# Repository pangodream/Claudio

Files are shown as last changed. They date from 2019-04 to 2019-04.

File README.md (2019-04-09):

# Claudio
Claudio is a wake up alarm based on ESP32 by Espressif Systems and programmed with Arduino IDE

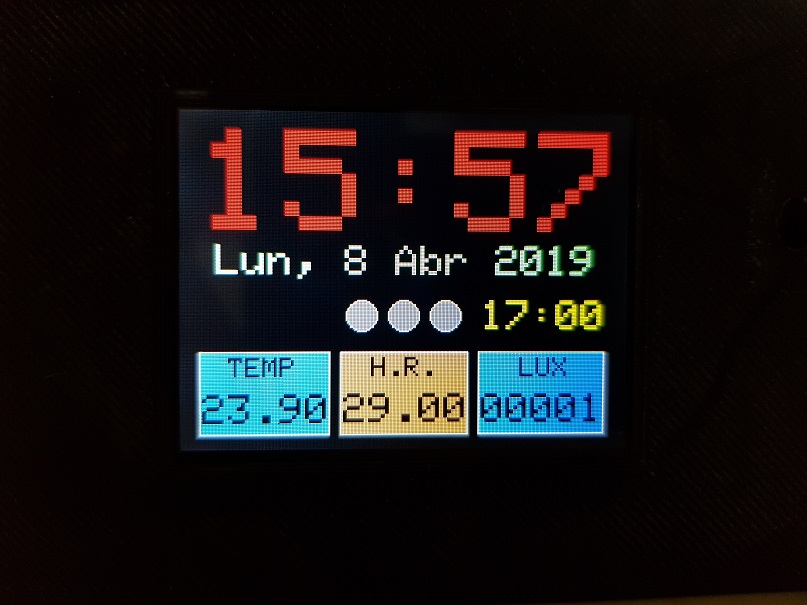
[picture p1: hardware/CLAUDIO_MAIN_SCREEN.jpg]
Claudio Main Screen


Folders:

/          Arduino IDE code

/box       Prototype print 3d files

/hardware  Hardware pictures

More info and demos at: https://www.youtube.com/watch?v=NURag-YYxIY

# WIRING DIAGRAM
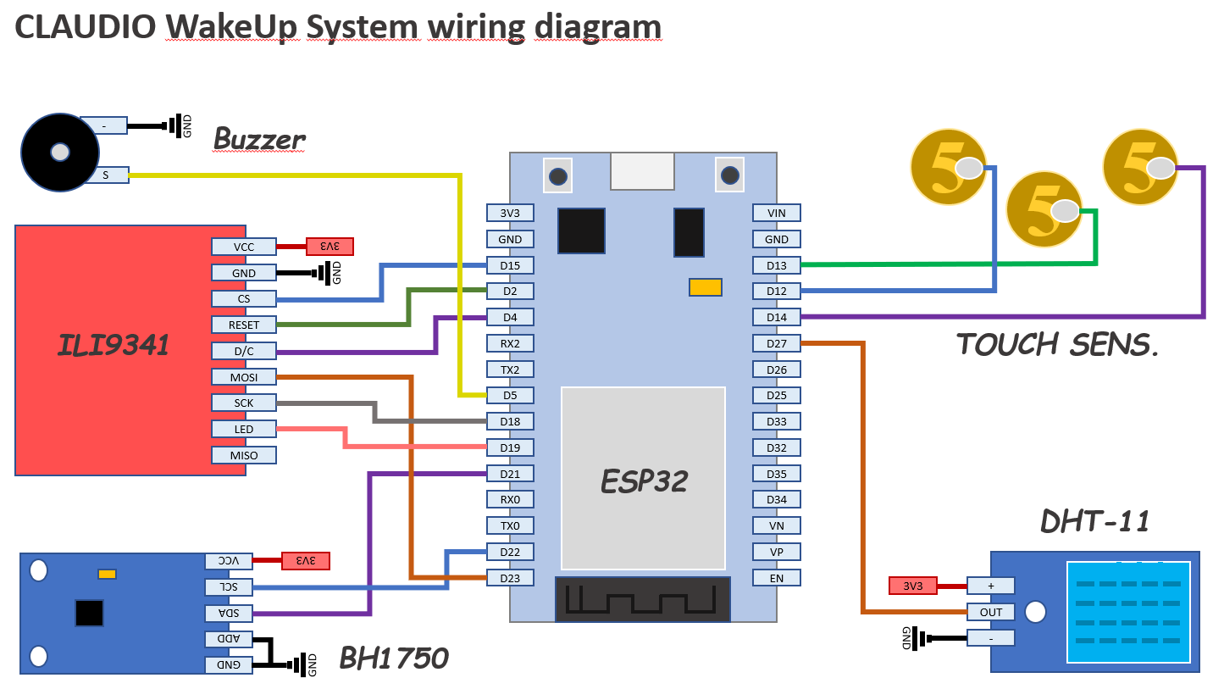
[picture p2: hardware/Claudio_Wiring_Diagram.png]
Claudio Main Screen


# REMOTE CONFIGURATION
By default, Claudio is listening on port 1234 for incoming connections. 

These connections allow a remote system to configure or perform some actions on the system. (Change parameters, Set alarm time, Deactivate alarm, ...)

Once the remote client is connected to claudio, commands are sent concatenated to items and values all in upper case. 

For instance, if we want to know the number of beeps to sound during an alarm, we must use the command GET followed by the item ALBEEP:
```bash
GETALBEEP
```
 If all succeed, the system will reply
```bash
90
```
which is the value cofigured for this parameter. Otherwise, the system could reply "Invalid Command" or "Invalid Item"

If we want to change the value of this parameter, for instance to 120, we should send
```bash
SETALBEEP120
```
and the system should reply
```bash
OK
```

## Available commands 
**GET**
Retrieves the value of the specified item.

**SET**
Stores the specified value in the specified item.

**GET**
Retrieves all the items value in a concatenated string ITEM1 + VALUE1 + ; + ... + ITEMn + VALUEn + ; 

For instance:
```bash
BOOTWT5;TOUCHR120;THTCHR70;THTCHM65;THTCHL65;LTCHTH12;...
```

**RST**
Reboot the system.

**TSS**
Stops and deactivates alarm, even while alarm is being executed.

## Available items
**BOOTWT**

Number of seconds (aprox.) to wait after boot screen to start the normal operation

EEPROM stored: Yes

Default value: 20

**TOUCHR**

Number of readings to calculate sensor capacitance average value

EEPROM stored: Yes

Default value: 120

**THTCHR**

Average capacitance threshold value for Right sensor. Under this value the sensor is considered activated

EEPROM stored: Yes

Default value: 70

**THTCHM**

Average capacitance threshold value for Middle sensor. Under this value the sensor is considered activated

EEPROM stored: Yes

Default value: 65

**THTCHL**

Average capacitance threshold value for Left sensor. Under this value the sensor is considered activated

EEPROM stored: Yes

Default value: 65

**LTCHTH**

Long touch threshold. Number of tenths of a second to consider a sensor has been long touched.

EEPROM stored: Yes

Default value: 12   (1.2 secs)

**SNZMIN**

Number of minutes to postpone alarm time (Snooze)

EEPROM stored: Yes

Default value: 9

**ALBEEP**

Number of beeps to sound during alarm

EEPROM stored: Yes

Default value: 90

**MAXLUX**

Maximum lux value to take into account. Above this any value is just considered maximum value.

When ambient light reaches this value, the display backlight is set to 100% power. 

EEPROM stored: Yes

Default value: 20

**MINLUX**

Minimum lux value to take into account. Below this any value is just considered minimum value.

When ambient light goes down to this value, the display backlight is set to Minimun Brightness value. (see next item))

EEPROM stored: Yes

Default value: 0

**MINBRG**

When ambient light reaches its minimum value, display backlight power is set to this value.

This is commonly used to set the backlight level we want while sleeping. 

EEPROM stored: Yes

Default value: 10

**ALARHO**

Defines the hour part of alarm time 

EEPROM stored: No

Default value: No default value

**ALARMI**

Defines the minutes part of alarm time

EEPROM stored: No

Default value: No default value

**DOALAR**

Switch ON/OFF alarm by sending 1/0 value for this item

EEPROM stored: No

Default value: No default value

**ONALAR**

Indicates whether the alarm is beeping or not. As well, it stops alarm beeping if its value is set to 0

EEPROM stored: No

Default value: No default value

To test remote configuration capabilities you can use Claudio Remote, an Android app to change configuration values easily:
https://github.com/pangodream/ClaudioRemote

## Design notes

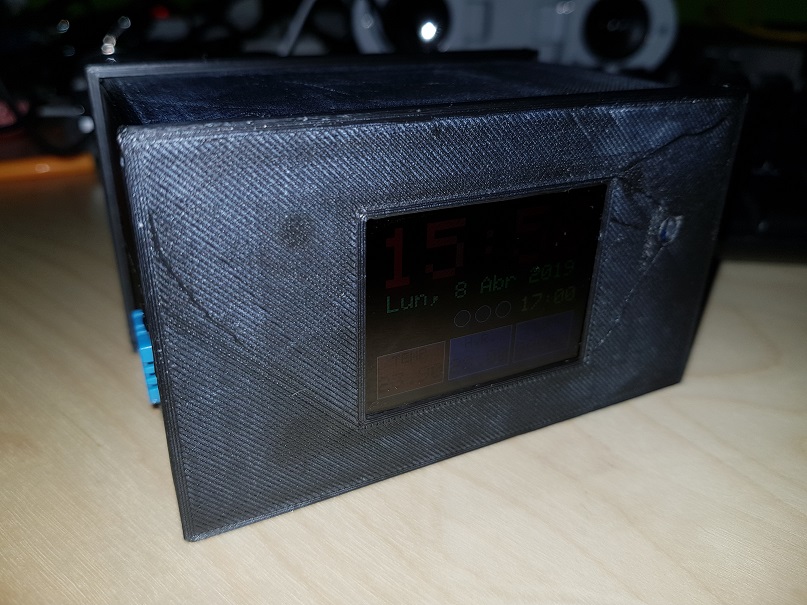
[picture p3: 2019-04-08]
hardware/CLAUDIO_PROTOTYPE_MOUNTED.jpg

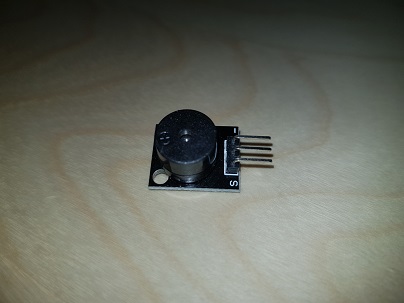
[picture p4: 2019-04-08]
hardware/PASSIVE_BUZZER.jpg

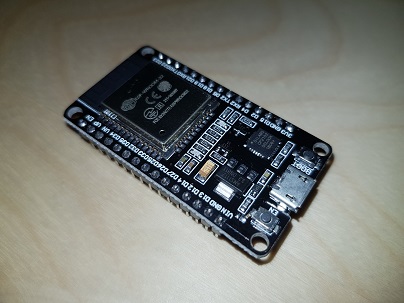
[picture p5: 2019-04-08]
hardware/ESP32_DEV_BOARD.jpg

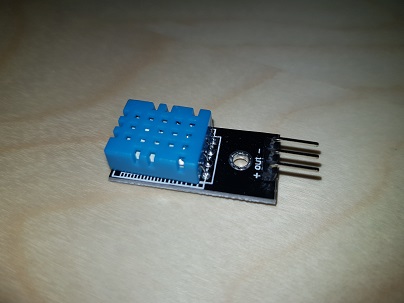
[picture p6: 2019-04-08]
hardware/DHT11_TEMP_HUMID_SENSOR.jpg

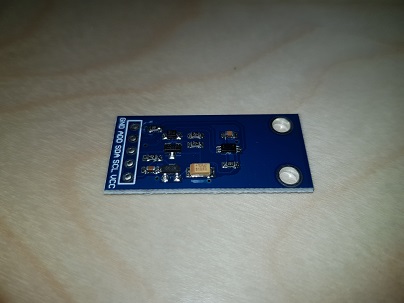
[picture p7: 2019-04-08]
hardware/BH1750FVI_LUX_METER.jpg

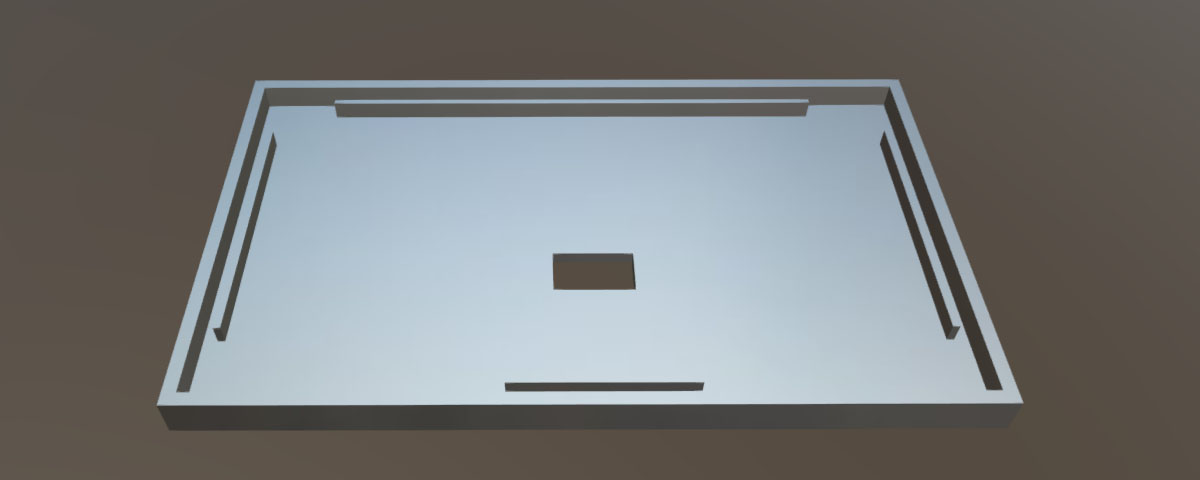
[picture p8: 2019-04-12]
box/ClaudioBoxBack.jpg

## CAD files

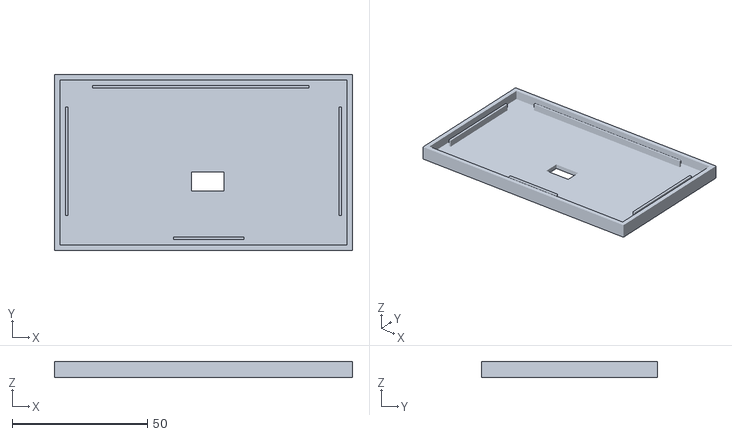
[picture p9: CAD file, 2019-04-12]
box/ClaudioBoxBack.stl
110.0 x 65.0 x 6.00

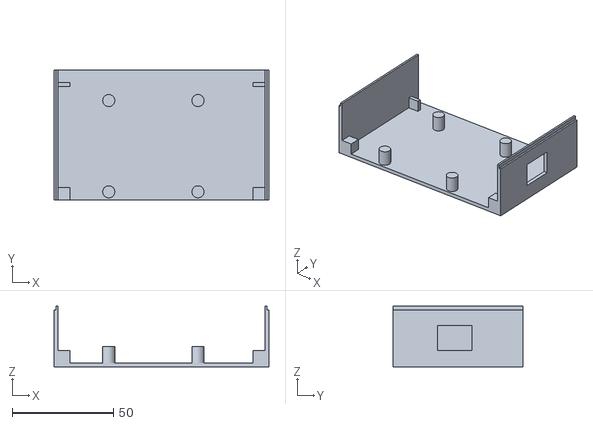
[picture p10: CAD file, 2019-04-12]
box/ClaudioBoxBase.stl
106.0 x 64.0 x 30.0

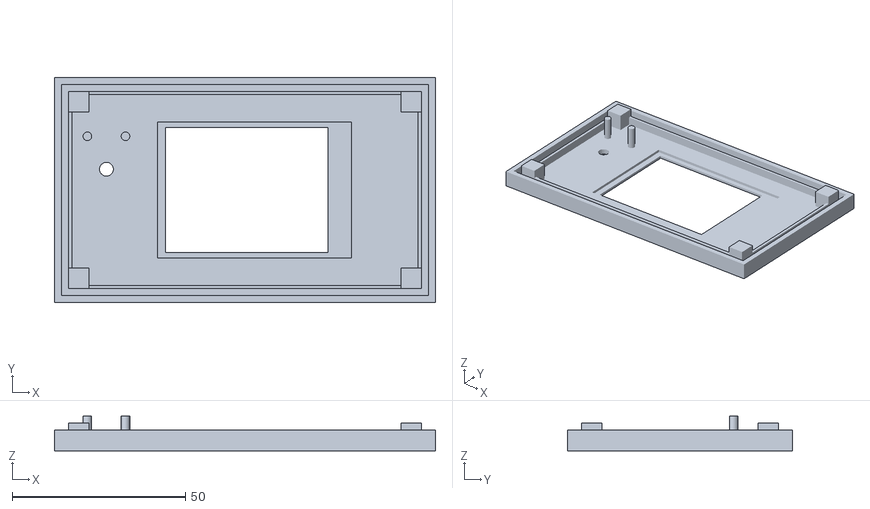
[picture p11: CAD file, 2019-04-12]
box/ClaudioBoxFront.stl
110.0 x 65.0 x 10.0

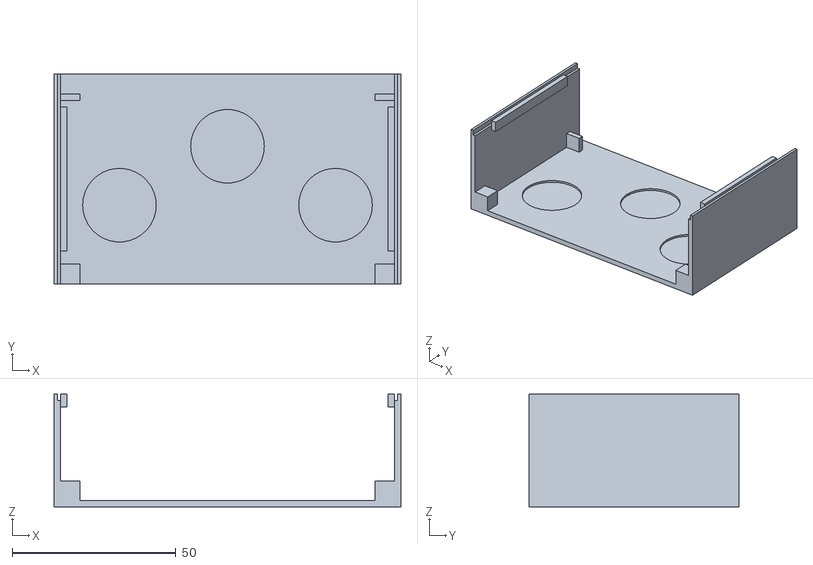
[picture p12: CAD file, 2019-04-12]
box/ClaudioBoxCover.stl
106.0 x 64.0 x 34.5

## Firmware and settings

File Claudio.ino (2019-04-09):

/**
 * GLOBAL PIN CONFIGURATION
 */

const int TFT_CS = 15;
const int TFT_DC = 4;
const int TFT_MOSI = 23;
const int TFT_SLK = 18;
const int TFT_RST = 2;
const int TFT_LED = 19;     
const int BUZZER = 5; 
const int LUX_SDA = 21;
const int LUX_SCL = 22;
const int DHT_OUT = 27;
/**
 * EEPROM libraries and resources
 */
#include "EEPROM.h"
#define EEPROM_SIZE 64
 
/**
 * ILI9341 TFT libraries and resources
 */
#include "SPI.h"
#include "Adafruit_GFX.h"
#include "Adafruit_ILI9341.h"
//                                      cs  dc  mosi slk rst
Adafruit_ILI9341 tft = Adafruit_ILI9341(TFT_CS, TFT_DC, TFT_MOSI, TFT_SLK, TFT_RST);

#define ILI9341_LCYAN   0x0418
#define ILI9341_LORANGE 0xFC08
#define ILI9341_LGREEN  0x87F0
#define ILI9341_LGRAY   0x8410

/**
 * BH1750 Lux meter libraries and resources
 */
#include <BH1750FVI.h>
// Create the Lightsensor instance
BH1750FVI LightSensor(BH1750FVI::k_DevModeContHighRes); 

/**
 * DHT-11 Temp and humidity sensor  libraries and resources
 */
#include "DHT.h"
#define DHTTYPE DHT11
DHT dht(DHT_OUT, DHTTYPE);       

/**    
 *  WIFI Libraries and resources   
 */
#include <WiFi.h>
//Absolute path to file containing WiFi credentials
//const char* ssid       = "MyApSSID";
//const char* password   = "MyApPassphrase";
#include <c:\datos\desarrollo\arduino\credentials.h>
const int connTimeout = 10; //Seconds

WiFiServer wifiServer(1234);


/** 
 *  TIME libraries and resources
 */
#include "time.h"
const char* ntpServer = "pool.ntp.org";
const long  gmtOffset_sec = 3600;
const int   daylightOffset_sec = 3600;
 
/**
 * PWM Constants
 */
const int freq = 5000;
const int tftledChannel = 0;
const int resolution = 8;
/**
 * TFT Display Constants 
 */
const int xTime = 14;
const int yTime = 14;
const int tftBG = ILI9341_BLACK;
const int tftTimeFG = ILI9341_RED;


 
/**
 * GLOBALS
 */
String   prevTime = "";
String   currTime = "";
String   prevDate = "";
String   currDate = ""; 
uint16_t prevLux = 0;
uint16_t currLux = 0;
float    prevTemp = 0;
float    currTemp = 0;
float    prevHumi = 0;
float    currHumi = 0;
bool     onWifi = false;
String   weekDays[] = {"", "Lun", "Mar", "Mie", "Jue", "Vie", "Sab", "Dom"};
String   months[] = {"", " Ene ", "Feb", "Mar", "Abr", "May", "Jun", "Jul", "Ago", "Sep", "Oct", "Nov", "Dic"};
int      pinTouchR = 14; 
int      pinTouchM = 13; 
int      pinTouchL = 12;
int      statusTouchR = 0;
int      statusTouchM = 0;
int      statusTouchL = 0;
ulong    lastTouchR;
ulong    lastTouchM;
ulong    lastTouchL;
bool     doAlarm;
String   alarmTime;
bool     onAlarm;
bool     waitingToTouch = false;
bool     onConfig = false;

//Configurable values
int      bootWait; //Seconds
int      touchReadings;
int      thresholdTouchR; 
int      thresholdTouchM; 
int      thresholdTouchL;
int      longTouchThreshold; // Tenths of second
int      snoozeMinutes;
int      alarmBeeps;
byte     maxLux;
byte     minLux;
byte     minBrightness;



void setup() {
  /**
   * Serial port
   */
  Serial.begin(115200);
  
  /**
   * EEPROM
   */
  EEPROM.begin(EEPROM_SIZE);
  /**
   * Loads EEPROM configuration
   */
  loadConfiguration();
  
  /**
   * TFT DISPLAY
   */
  //Background light PWM
  ledcSetup(tftledChannel, freq, resolution);
  ledcAttachPin(TFT_LED, tftledChannel);
  //Start with high intensity 
  setBGLuminosity(255);
  tft.begin();
  tft.setRotation(3);
  yield();
  
  //Boot screen
  tft.fillScreen(ILI9341_BLACK);
  yield();
  tft.setTextSize(4);
  tft.setTextColor(ILI9341_LORANGE);
  tft.println("Claudio!");
  tft.setTextSize(1);
  tft.setTextColor(ILI9341_WHITE);
  tft.println("");
  tft.println("Booting...");
  tft.println("Setting up devices...");
  /**
   * BUZZER
   */
  pinMode(BUZZER, OUTPUT); 
  /**
   * Light sensor
   */
  LightSensor.begin(); 
  /**
   * Temperature and humidity sensor
   */
  dht.begin();    
  tft.print("Connecting to WiFi AP "); 
  tft.println(ssid);     
  /**
   * Wifi connect
   */
  wifiConnect();
  if(onWifi == true){
    tft.print("   Connection succeed, obtained IP ");
    tft.println(WiFi.localIP());
  }else{
    tft.println("   Connection failed. Unexpected operation results.");
  }
  tft.println("Obtaining NTP time from remote server...");
  /**
   * NTP Time
   */
  getNtpTime();
  delay(100); //We need a delay to allow info propagation
  
  /**
   * Wifi Server for configuration
   */
  tft.println("Starting remote configuration server...");
  wifiServer.begin();

  tft.println("End of booting process.");
   
  //Wait twenty seconds or until the user touches a button
  waitTouch(bootWait);

  //Prepare screen for normal operation
  setBGLuminosity(0);
  tft.fillScreen(ILI9341_BLACK);
  yield();

  //Paint elements
  displayTime();
  displayDate();
  displayAlarm();
  displayTemp();
  displayHumi();
  displayLux();
  displayButton(0, false, false);
  displayButton(1, false, false);
  displayButton(2, false, false);
  setBGLuminosity(255);
  /** 
   *  TESTING
   */


}

void loop() {
  getCurrentLux();
  getCurrentTemp();
  getCurrentHumi();
  refreshTime();
  readTouch();
  configMode();
  delay(100);
}

/**
 * Checks for next alarm in queue
 */
void checkAlarm(){
  //TODO: Check in queue what is the nex alarm to be activated...
  alarmTime = hourMinuteToTime(getAlarmHour(), getAlarmMinute()); 
  doAlarm = true;
  displayAlarm(); 
}
/**
 * Connects to WIFI
 */

bool wifiConnect(){
  onWifi = false;
  int retries = 0;
  Serial.printf("Connecting to %s ", ssid);
  WiFi.begin(ssid, password);
  while (WiFi.status() != WL_CONNECTED) {
      delay(500);
      Serial.print(".");
      retries++;
      if(retries == (connTimeout * 2)){
        Serial.println(" TIMEOUT");
        break;
      }
  }
  if(WiFi.status() == WL_CONNECTED){
    onWifi = true;
    Serial.println(" CONNECTED");
  }
  return onWifi;
}
/**
 * Obtains time from NTP server
 */
bool getNtpTime(){
  bool result = false;
  if(onWifi == true){
    configTime(gmtOffset_sec, daylightOffset_sec, ntpServer);
    result = true;
  }else{
    Serial.println("getNtpTime: Not connected to wifi!"); 
  }
  return result;
}

/**
 * Returns day of week (1-Mon, 2-Tue, ...., 7-Sun)
 */
int getDayOfWeek(){ //1-Mon, 2-Tue, ...., 7-Sun
  int wDay;
  time_t now;
  struct tm * timeinfo;
  time(&now);
  timeinfo = localtime(&now); 
  wDay = timeinfo->tm_wday;
  if(wDay == 0){
    wDay = 7;
  }
  return wDay;
}
/**
 * Adds a number of snooze minutes to s String time
 */
String addSnooze(String sTime, int snooze){
  int hour;
  int minute;
  int tMinutes;
  int tHours;
  String newTime;
  char cTime[5]=" ";
  hour = sTime.substring(0,2).toInt();
  minute = sTime.substring(3,5).toInt();
  tMinutes = (minute+snooze) % 60;
  tHours = (hour + ((minute+snooze) / 60)) % 24;

  sprintf(cTime, "%02d:%02d", tHours, tMinutes); 
  newTime = (char*)cTime;
  return newTime;
}
/**
 * Returns a string formatted HH:MM based on hours and minutes
 */
String hourMinuteToTime(int hour, int minute){
  String sTime;
  char cTime[5]=" ";
  sprintf(cTime, "%02d:%02d", hour, minute); 
  sTime = (char*)cTime; 
  return sTime;
}
/*
 * Returns current time in HH:MM format
 */
String refreshTime(){
  //Time
  time_t now;
  struct tm * timeinfo;
  time(&now);
  timeinfo = localtime(&now); 
  prevTime = currTime;
  currTime = hourMinuteToTime(timeinfo->tm_hour, timeinfo->tm_min); 
  if(prevTime != currTime){
    timeChanged(prevTime, currTime);
    //If time has changed, lets check if date has changed too
    //Date
    int wDay;
    wDay = timeinfo->tm_wday;
    if(wDay == 0){
      wDay = 7;
    }
    String calDate = "";
    char cDate[30]=" ";
    //Serial.println(weekDays[wDay]);
    //sprintf(cDate, "%s, %i de %s de %i", weekDays[wDay], timeinfo->tm_mday, months[(timeinfo->tm_mon + 1)],(timeinfo->tm_year + 1900)); 
    calDate = calDate + weekDays[wDay];
    calDate = calDate + ", ";
    calDate = calDate + timeinfo->tm_mday;
    calDate = calDate + " ";
    calDate = calDate + months[(timeinfo->tm_mon + 1)];
    calDate = calDate + " ";    
    calDate = calDate + (timeinfo->tm_year + 1900);
    if(calDate.length() == 21){
      calDate = " " + calDate;
    }
    prevDate = currDate;
    currDate = calDate;
    if(prevDate != currDate){
      dateChanged(prevDate, currDate);
    }
  }
}

/**
 * Displays time string erasing the previous one
 */
void displayTime(){
  tft.setTextSize(10);
  tft.setCursor(xTime, yTime);
  tft.setTextColor(tftBG);
  yield();
  tft.println(prevTime);
  yield();
  tft.setCursor(xTime, yTime);
  tft.setTextColor(tftTimeFG);
  yield();
  tft.println(currTime);
  yield();
}
/**
 * Displays date string 
 */
void displayDate(){
  tft.fillRect(14, 94, 192, 30, ILI9341_BLACK);
  tft.setTextSize(3);
  tft.setCursor(26, 94);
  tft.setTextColor(ILI9341_LGREEN);
  yield();
  tft.println(currDate);
}
/**
 * Displays temperature
 */
void displayTemp(){
  int bgColor = 0;
  if(currTemp == prevTemp){
    bgColor = ILI9341_LGREEN;
  }else if(currTemp < prevTemp){
    bgColor = ILI9341_LCYAN;
  }else{
    bgColor = ILI9341_LORANGE;
  }
  
  tft.setTextColor(ILI9341_BLACK);
  yield();
  tft.fillRect(14, 170, 92, 60, bgColor);
  tft.drawRect(14, 170, 92, 60, ILI9341_WHITE);
  yield();
  tft.setTextSize(2);
  tft.setCursor(34, 174);
  tft.print("TEMP");
  tft.setTextSize(3);
  tft.setCursor(16, 200);
  tft.print(currTemp);
}
/**
 * Displays relative humidity
 */
void displayHumi(){
  int bgColor = 0;
  if(currHumi == prevHumi){
    bgColor = ILI9341_LGREEN;
  }else if(currHumi < prevHumi){
    bgColor = ILI9341_LCYAN;
  }else{
    bgColor = ILI9341_LORANGE;
  }
  tft.setTextColor(ILI9341_BLACK);
  yield();
  tft.fillRect(113, 170, 92, 60, bgColor);
  tft.drawRect(113, 170, 92, 60, ILI9341_WHITE);
  yield();
  tft.setTextSize(2);
  tft.setCursor(135, 174);
  tft.print("H.R.");
  tft.setTextSize(3);
  tft.setCursor(115, 200);
  tft.print(currHumi);
}
/**
 * Displays lux 
 */
void displayLux(){
  int bgColor = 0;
  if(currLux == prevLux){
    bgColor = ILI9341_LGREEN;
  }else if(currLux < prevLux){
    bgColor = ILI9341_LCYAN;
  }else{
    bgColor = ILI9341_LORANGE;
  }
  tft.setTextColor(ILI9341_BLACK);
  yield();
  tft.fillRect(212, 170, 92, 60, bgColor);
  tft.drawRect(212, 170, 92, 60, ILI9341_WHITE);
  yield();
  tft.setTextSize(2);
  tft.setCursor(242, 174);
  tft.print("LUX");
  tft.setTextSize(3);
  tft.setCursor(214, 200);
  char cLux[5]=" ";
  sprintf(cLux, "%05d", currLux); 
  //currTime = (char*)cTime;
  tft.print(cLux);
}
/**
 * Displays Alarm Time 
 */
void displayAlarm(){
  if(doAlarm == true){
    tft.setTextColor(ILI9341_YELLOW);
  }else{
    tft.setTextColor(ILI9341_LGRAY);
  }
  yield();
  tft.fillRect(212, 129, 92, 36, ILI9341_BLACK);
  yield();
  tft.setTextSize(3);
  tft.setCursor(214, 133);
  tft.print(alarmTime);
}
/**
 * Sets button status
 * 0 - Left
 * 1 - Middle
 * 2 - Right
 */
void displayButton(int button, bool activated, bool longTouch){
  int bgColor;
  int x;
  if(activated == true){
    if(longTouch == true){
      bgColor = ILI9341_RED;
    }else{
      bgColor = ILI9341_YELLOW;
    }
  }else{
    bgColor = ILI9341_LGRAY;
  }
  yield();
  x = 128 + (button * 30);
  tft.fillCircle(x, 144, 11,bgColor);
  tft.drawCircle(x, 144, 11,ILI9341_WHITE);
  yield();
}


/**
 * Sets TFT background luminosity (0-255)
 */
void setBGLuminosity(int level){
  ledcWrite(tftledChannel, level);
}
/**
 * Plays beep on buzzer a number of times
 */
void playBuzzer(int times){
  onAlarm = true;
  for(int t=0; t< times; t++){
    if(onAlarm == false){
      break;
    }
    for(int i=0; i< 200; i++)
    {
      digitalWrite(BUZZER, HIGH);
      delay(1);
      digitalWrite(BUZZER, LOW);
      delay(1);
    }
    //Read touch sensor to check if alarm is stopped manually
    readTouch();
    //Check if remote management is requested (to stop alarm remotely)
    configMode();
    delay(10);
  }
}
/**
 * Waits for the user to touch a button
 * Timeout in seconds (aprox.)
 */
void waitTouch(int timeout){ 
  waitingToTouch = true;
  for(int t=0; t< (timeout * 3.6); t++){
    readTouch();
    if(waitingToTouch == false){
      break;
    }
    delay(100);
  }
}
/**
 * Returns ambient light luxes 
 */
uint16_t getCurrentLux(){
  prevLux = currLux;
  currLux = LightSensor.GetLightIntensity();
  if(prevLux != currLux){
    luxChanged(prevLux , currLux);
  }
  return currLux;
}
/**
 * Calculates and sets screen backlight brightness
 */
void calculateAndSetBGLuminosity(uint16_t currLux){
  int finalLux = currLux;
  if(finalLux > maxLux){
    finalLux = maxLux;
  }
  if(finalLux < minLux){
    finalLux = minLux;
  }
  double levelsWidth = maxLux - minLux;
  double level = finalLux - minLux;
  double ratio = level / levelsWidth;
  double brightnessWidth = 255 - minBrightness;
  int brightnessValue = (brightnessWidth * ratio) + minBrightness;
  setBGLuminosity(brightnessValue);
}
/**
 * Returns temperature
 */
float getCurrentTemp(){
  prevTemp = currTemp;
  currTemp = dht.readTemperature();;
  if(prevTemp != currTemp){
    tempChanged(prevTemp , currTemp);
  }
  return currTemp;
}
/**
 * Returns humidity
 */
float getCurrentHumi(){
  prevHumi = currHumi;
  currHumi = dht.readHumidity();
  if(prevHumi != currHumi){
    humiChanged(prevHumi , currHumi);
  }
  return currHumi;
}
/**
 * Reads touch buttons status and launches events
 */
void readTouch(){
  int avgTouchR = 0; int avgTouchM = 0; int avgTouchL = 0;
  for(int i=0; i< touchReadings; i++){
    avgTouchR += touchRead(pinTouchR);
    avgTouchM += touchRead(pinTouchM);
    avgTouchL += touchRead(pinTouchL);
  }   
  yield();
  avgTouchR = avgTouchR / touchReadings;
  avgTouchM = avgTouchM / touchReadings;
  avgTouchL = avgTouchL / touchReadings;

  //LEFT BUTTON  
  if(avgTouchL < thresholdTouchL){
    if(statusTouchL == 0){
      lastTouchL = millis();
      touchL();
      statusTouchL = 1;
    }else if(statusTouchL == 1){
      if((millis() - lastTouchL) > (longTouchThreshold * 100)){
        statusTouchL = 2;
        touchLongL();
      }
    }  
  }else{
    if(statusTouchL != 0){
      releaseL();
    }
    statusTouchL = 0;    
  }    
  //MIDDLE BUTTON  
  if(avgTouchM < thresholdTouchM){
    if(statusTouchM == 0){
      lastTouchM = millis();
      touchM();
      statusTouchM = 1;
    }else if(statusTouchM == 1){
      if((millis() - lastTouchM) > (longTouchThreshold * 100)){
        statusTouchM = 2;
        touchLongM();
      }
    }  
  }else{
    if(statusTouchM != 0){
      releaseM();
    }
    statusTouchM = 0;    
  }  
  //RIGHT BUTTON  
  if(avgTouchR < thresholdTouchR){
    if(statusTouchR == 0){
      lastTouchR = millis();
      touchR();
      statusTouchR = 1;
    }else if(statusTouchR == 1){
      if((millis() - lastTouchR) > (longTouchThreshold * 100)){
        statusTouchR = 2;
        touchLongR();
      }
    }  
  }else{
    if(statusTouchR != 0){
      releaseR();
    }
    statusTouchR = 0;    
  }  
}

/**
 *  EVENTS
 */ 
/**
 * Event for change of time HH:MM
 */
void timeChanged(String prevTime, String currTime){
  //Serial.println("timeChanged event fired!");
  displayTime();
  if(currTime == alarmTime){
    if(doAlarm == true){
      if(onAlarm == false){
        playBuzzer(alarmBeeps);
        doAlarm = false;
      }
    }
  }
}
/**
 * Event for change of date weekDay, day de Month de Year
 */
void dateChanged(String prevDate, String currDate){
  //Serial.print("dateChanged event fired! ");
  //Serial.println(currDate);
  displayDate();
  //New day, lets check for the next alarm
  checkAlarm();
}
/**
 * Event for change of ambient light
 */
void luxChanged(uint16_t prevLux, uint16_t currLux){
  //Serial.print("luxChanged event fired! ");
  //Serial.println(currLux);
  displayLux();
  calculateAndSetBGLuminosity(currLux);
}

/**
 * Event for change of temperature
 */
void tempChanged(float prevTemp, float currTemp){
  //Serial.print("tempChanged event fired! ");
  //Serial.println(currTemp);
  displayTemp();
}
/**
 * Event for change of humidity
 */
void humiChanged(float prevHumi, float currHumi){
  //Serial.println("humiChanged event fired!");
  displayHumi();
  
}
/**
 * Touch buttons events
 */
void touchR(){
  Serial.println("Touch Right");
  displayButton(2, true, false);
  touchAny();
}
void touchLongR(){
  Serial.println("Touch Long Right");
  displayButton(2, true, true);
  touchLongAny();
}
void releaseR(){
  Serial.println("Release Right");
  displayButton(2, false, false);
  releaseAny();
}

void touchM(){
  Serial.println("Touch Middle");
  displayButton(1, true, false);
  touchAny();
}
void touchLongM(){
  Serial.println("Touch Long Middle");
  displayButton(1, true, true);
  touchLongAny();
}
void releaseM(){
  Serial.println("Release Middle");
  displayButton(1, false, false);
  releaseAny();
}

void touchL(){
  Serial.println("Touch Left");
  displayButton(0, true, false);
  touchAny();
}
void touchLongL(){
  Serial.println("Touch Long Left");
  displayButton(0, true, true);
  touchLongAny();
}
void releaseL(){
  Serial.println("Release Left");
  displayButton(0, false, false);
  releaseAny();
} 

void touchAny(){
  waitingToTouch = false;
  if(onAlarm == true){
      onAlarm = false;
      doAlarm = false;
      displayAlarm();
  }
}
void touchLongAny(){
  Serial.println("Touch Long Any");
  //Extra alarma functionalities (Alarm Off, Alarm On and Snooze)
  //Check if event occurs during first alarm minute
  if(alarmTime == currTime){
    //Add Snooze time to alarmTime
    alarmTime = addSnooze(alarmTime, snoozeMinutes);
    doAlarm = true;
    displayAlarm();
  }else{
    //Switch On/Off alarm
    doAlarm = !doAlarm;
    displayAlarm();
  }

  //Only for testing!!!
  //Set alarm time equal to current time if left and right buttons are longTouched simultaneously
  if(statusTouchL == 2 && statusTouchR == 2){
    alarmTime = currTime;
    displayAlarm();
    timeChanged(currTime, currTime);
  }
}
void releaseAny(){

}
void configOn(){
  Serial.println("Entered config mode");
}
void configOff(){
  Serial.println("Exited config mode");
}


/**
 * Remote configuration
 */
void configMode(){
  String instruction = "";
  String reply = "";
  WiFiClient client = wifiServer.available();
  if (client) {
    onConfig = true;
    configOn();
    while (client.connected()) {
      while (client.available()>0) {
        char c = client.read();
        if(c == 10){
          reply = configExecute(instruction);
          instruction = "";
          client.println(reply);
        }else{
          instruction = instruction + c;
        }
        
      }
      delay(10);
    }
    client.stop();
    onConfig = false;
    configOff();
  }  
} 
String configExecute(String instruction){
  String command;
  String item;
  String value;
  int setValue;
  command = instruction.substring(0, 3);
  item = instruction.substring(3, 9);
  Serial.print("Remote config: ");Serial.println(instruction);
  if(command == "GET"){
      value = getConfigValue(item);
  }else if(command == "SET"){
      setValue = instruction.substring(9, 12).toInt();
      value = setConfigValue(item, setValue);
  }else if(command == "ALL"){
      value = getAllItems();   
  }else if(command == "RST"){
      ESP.restart();  
  }else if(command == "TSS"){
      onAlarm = false;
      doAlarm = false;  
      displayAlarm();
  }else{
      value = "Invalid command";
  }
  return value;
}
String getConfigValue(String item){
  String value;
  if(item == "BOOTWT"){
    value = (String) getBootWait();
  }else if(item == "TOUCHR"){
    value = (String) getTouchReadings();
  }else if(item == "THTCHR"){
    value = (String) getThresholdTouchR();
  }else if(item == "THTCHM"){
    value = (String) getThresholdTouchM();
  }else if(item == "THTCHL"){
    value = (String) getThresholdTouchL();
  }else if(item == "LTCHTH"){
    value = (String) getLongTouchThreshold();
  }else if(item == "SNZMIN"){
    value = (String) getSnoozeMinutes();
  }else if(item == "ALBEEP"){
    value = (String) getAlarmBeeps();
  }else if(item == "MAXLUX"){
    value = (String) getMaxLux();
  }else if(item == "MINLUX"){
    value = (String) getMinLux();
  }else if(item == "MINBRG"){
    value = (String) getMinBrightness();
  }else if(item == "ALARHO"){
    value = (String) getAlarmHour();
  }else if(item == "ALARMI"){
    value = (String) getAlarmMinute();
  }else if(item == "DOALAR"){
    value = (String) getDoAlarm();  
  }else if(item == "ONALAR"){
    value = (String) getOnAlarm();    
  }else{
    value = "Invalid item";
  }  
  return value;
}
String setConfigValue(String item, int setValue){
  String value = "OK";
  if(item == "BOOTWT"){
    setBootWait(setValue);
  }else if(item == "TOUCHR"){
    setTouchReadings(setValue);
  }else if(item == "THTCHR"){
    setThresholdTouchR(setValue);
  }else if(item == "THTCHM"){
    setThresholdTouchM(setValue);
  }else if(item == "THTCHL"){
    setThresholdTouchL(setValue);
  }else if(item == "LTCHTH"){
    setLongTouchThreshold(setValue);
  }else if(item == "SNZMIN"){
    setSnoozeMinutes(setValue);
  }else if(item == "ALBEEP"){
    setAlarmBeeps(setValue);
  }else if(item == "MAXLUX"){
    setMaxLux(setValue);
  }else if(item == "MINLUX"){
    setMinLux(setValue);
  }else if(item == "MINBRG"){
    setMinBrightness(setValue);
  }else if(item == "ALARHO"){
    setAlarmHour(setValue);
  }else if(item == "ALARMI"){
    setAlarmMinute(setValue);
  }else if(item == "DOALAR"){
    setDoAlarm(setValue);
  }else if(item == "ONALAR"){
    setOnAlarm(setValue);    
  }else{
    value = "Invalid item";
  }  
  return value;
}
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

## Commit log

2019-04-08 Improvements
    - Show minBrightness effects during configuration
    - During boot, at the end, switch off creen, load all the elements and switch it on
2019-04-08 Added wiring diagram
2019-04-08 Update readme with wiring diagram
2019-04-12 Box files updated
    [ClaudioBoxBack.stl, ClaudioBoxBase.stl, ClaudioBoxCover.stl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]
